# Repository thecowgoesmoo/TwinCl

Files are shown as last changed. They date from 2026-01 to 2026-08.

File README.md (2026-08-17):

# TwinCl
A modern clavinet design &amp; its digital twin
The instrument is designed in OpenSCAD.  A digital model is built and simulated in MATLAB.  WAV files are bundled into sfz (sforzando sample player VST) patches for play-testing instrument parameter variations.  It is intended to be built from low-cost and easily-sourced materials.

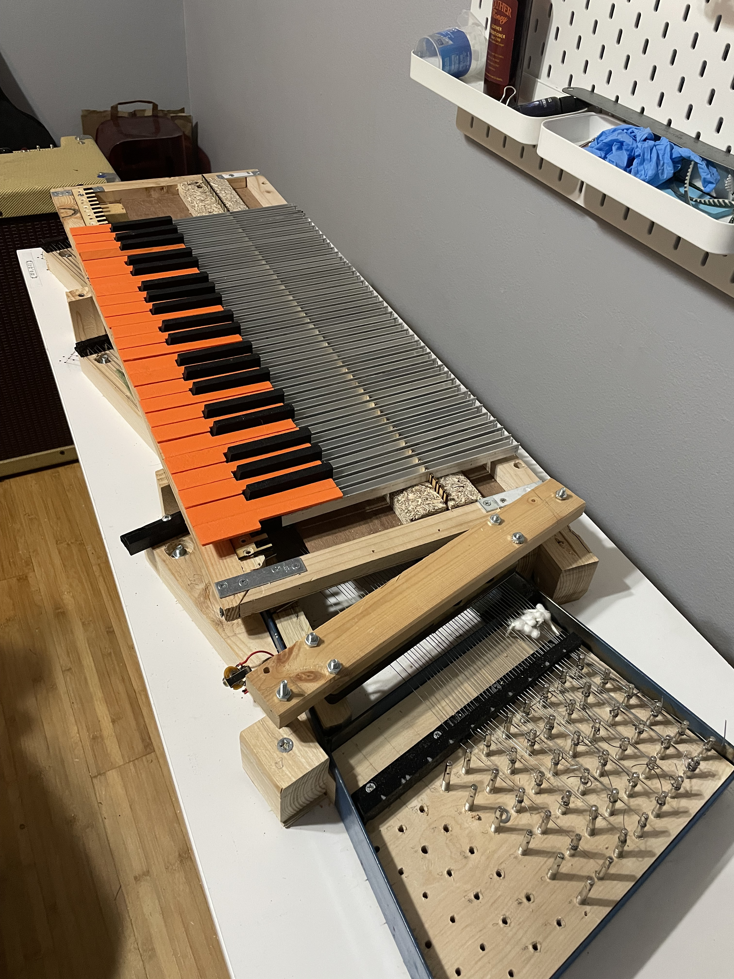
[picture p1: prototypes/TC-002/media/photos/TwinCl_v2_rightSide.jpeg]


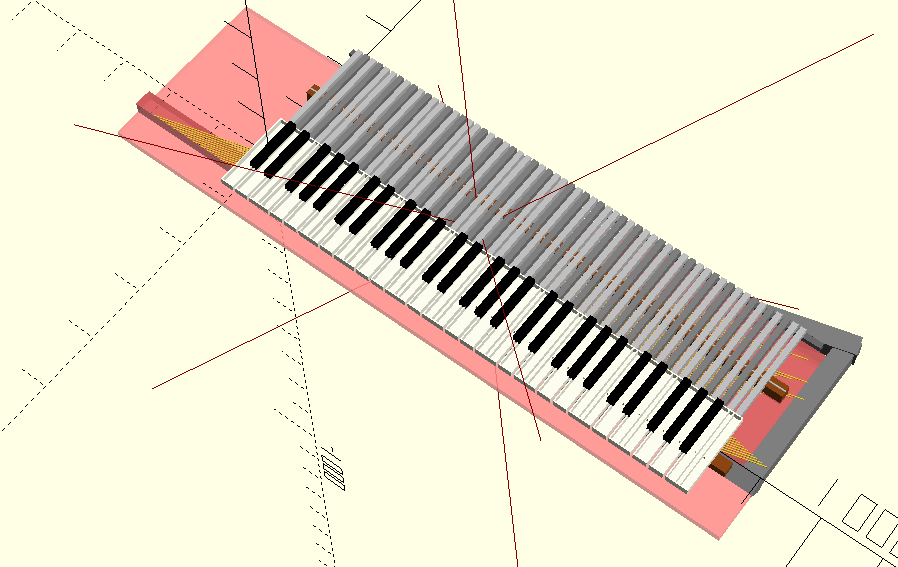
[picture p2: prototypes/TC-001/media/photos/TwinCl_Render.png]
Render


Innovators like Leo Fender imbued the electric guitar with flexibility at a price-point that enabled a several subsequent decades of musical development.  The electromechanical pianos of the mid 20th century introduced new sounds as well, but many factors (including complexity & cost) kept them from displacing the acoustic piano as completely as the electric guitar did for its arched hollow predecessors.  The advent of the ROM-based electronic keyboards in the 1980's dropped keyboard manufacturing costs by an order of magnitude while also bringing more convincing piano sounds to consumers.  As a result, nearly all remaining electromechanical keyboard instruments are refurbished holdovers from the 1950's to 1970's.  

Our intepretation of sound will always be rooted in the physical world, though.  And the vibrating string is the musical archetype.  With that motivation, I seek here to design an instrument modeled after the Clavinet with the following goals:

-Portable (target weight of 50 lbs or less)

-Affordable (bill of materials costing hundreds, not thousands)

-Low-cost manufacturing (target labor of less than 2 person-days)

-Re-use of commerically available materials where possible

-Parametric CAD scripts, to ease customization

-Explore collaborative design with AI LLM's

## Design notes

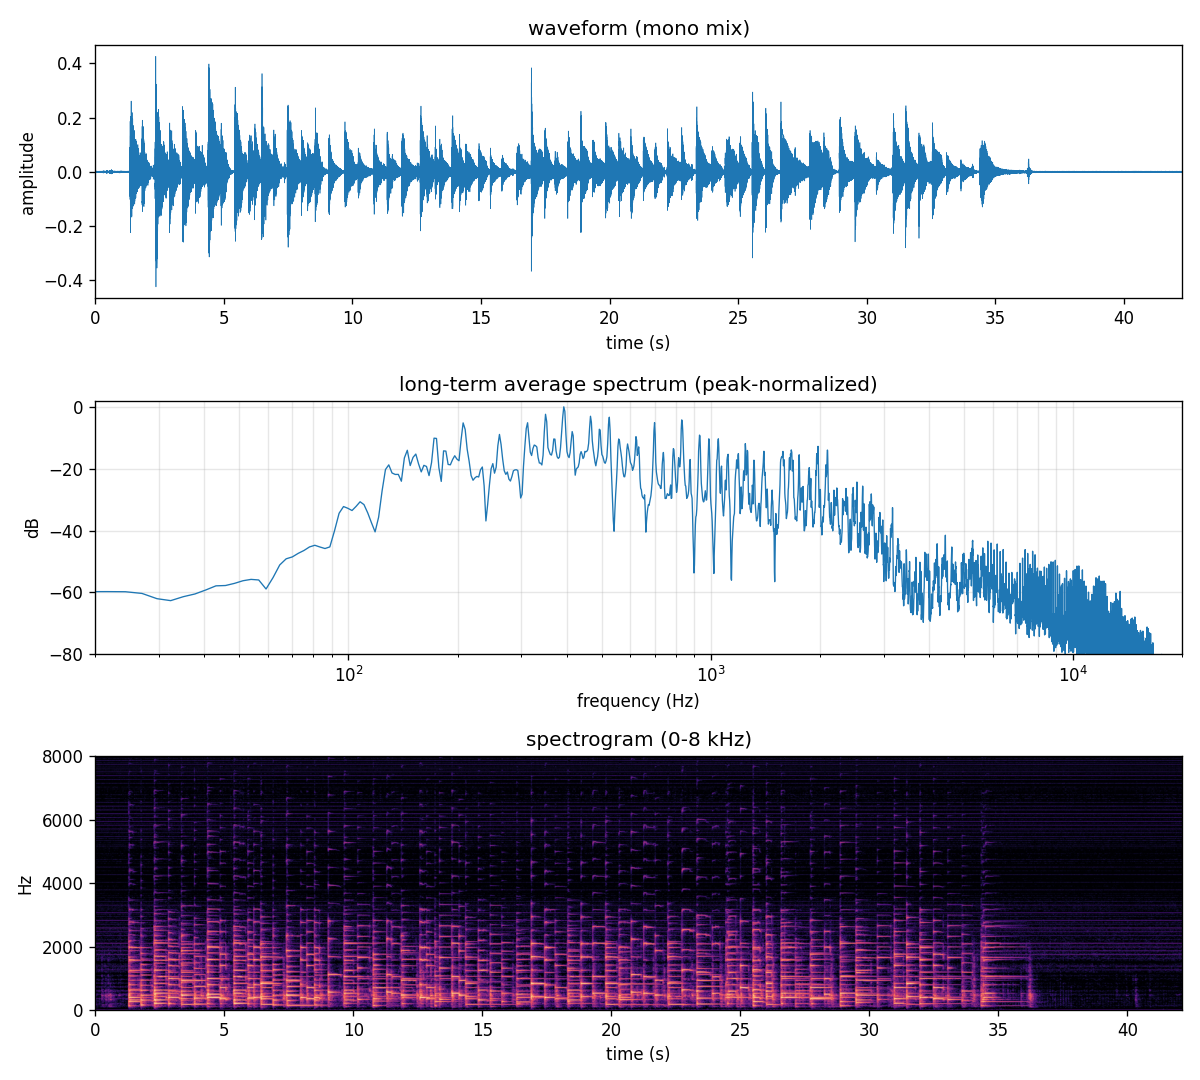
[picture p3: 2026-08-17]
tc002_overview.png

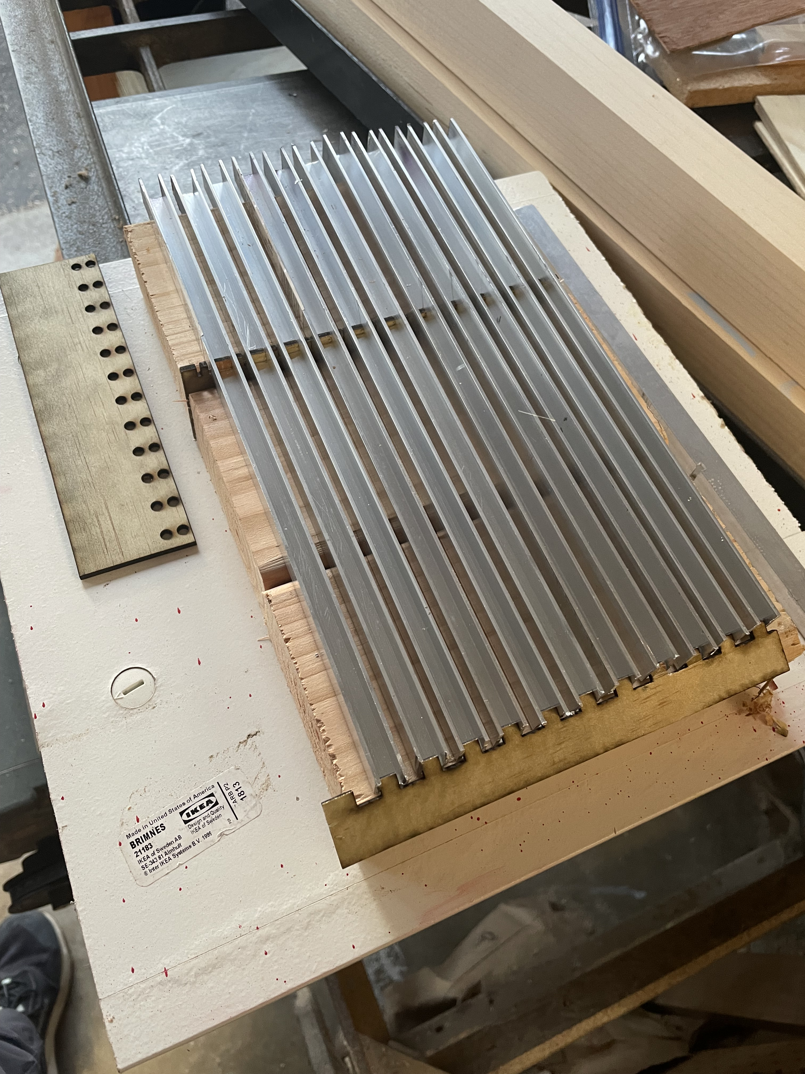
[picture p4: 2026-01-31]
prototypes/TC-001/media/photos/octave_keyChassis_mockup.jpeg

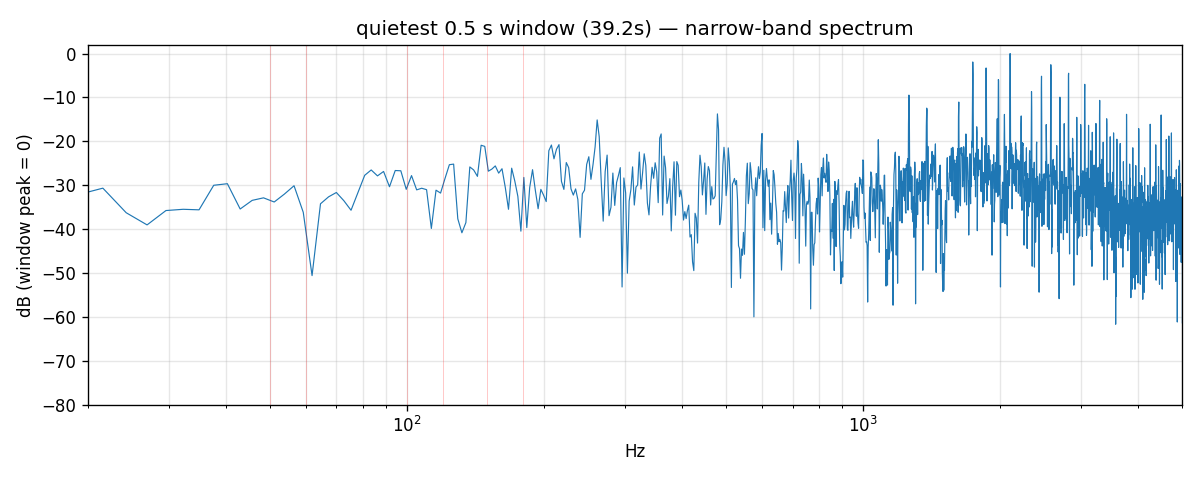
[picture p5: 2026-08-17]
tc002_quiet_spectrum.png

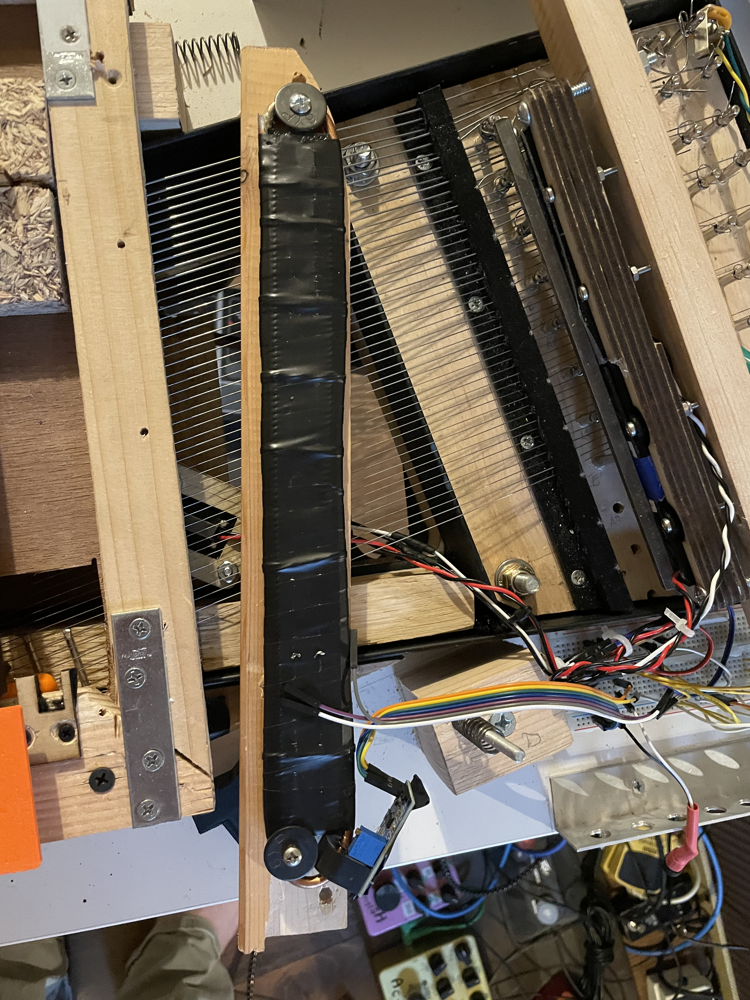
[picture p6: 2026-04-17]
prototypes/TC-002/media/photos/TwinCl_v2_CSTbasedPickup.jpeg

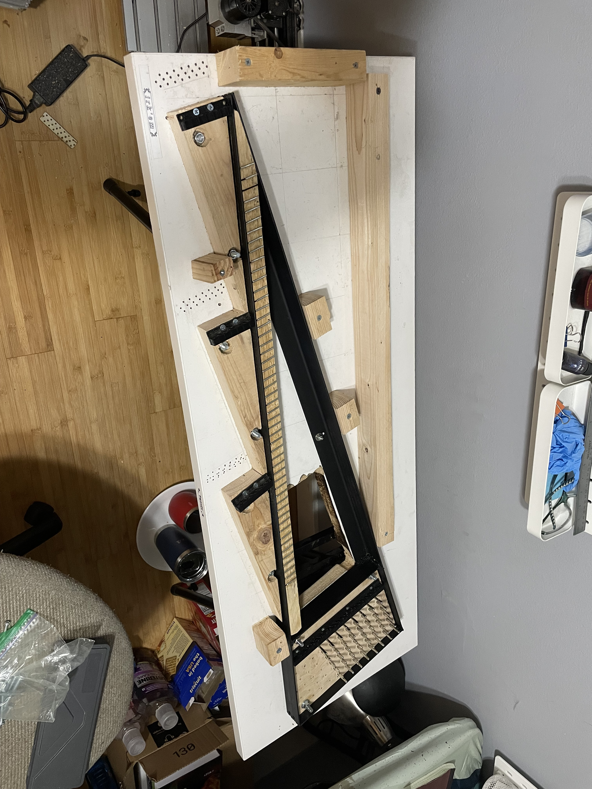
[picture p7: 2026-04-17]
prototypes/TC-002/media/photos/TwinCl_v2_HarpPUaccessCut.jpeg

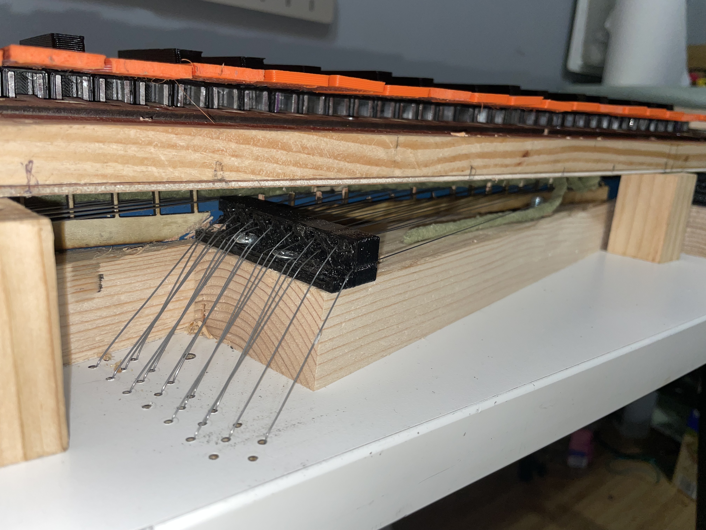
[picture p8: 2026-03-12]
prototypes/TC-002/media/photos/TwinCl_v2_stringEnds.jpeg

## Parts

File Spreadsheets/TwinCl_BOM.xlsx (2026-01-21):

Part name | Part detail | Quantity | Source link | Unit price | Line total price | Weight | Line total weight
String thick 1 | 0.036" wound electric guitar string | 3 | https://www.stringsandbeyond.com/daddario-electric-guitar-single-string-nw036.html | $1.79 | $5.37 | 0 |  | Prolly gotta use guitar strings
String thick 2 | 0.024" wound electric guitar string | 5 | https://www.stringsbymail.com/daddario-nw024-xl-nickel-wound-electric-string-024-gauge-single-4358.html | $1.59 | $7.95 | 0 |  | Prolly gotta use guitar strings
String thick 3 | 0.016" electric guitar string | 10 | https://www.ellismusic.com/p-1560-daddario-pl016-plain-steel-guitar-single-string-016.aspx | $1.50 | $15.00 | 0 |  | Much cheaper in bulk spools
String thick 4 | 0.0105" electric guitar string | 8 | https://www.musicstore.com/en_US/USD/D-Addario-NYS0105/art-GIT0040832-000 | $2.33 | $18.64 | 0 |  | Much cheaper in bulk spools
String thick 5 | 0.009" electric guitar string | 35 | https://www.stewmac.com/strings-and-accessories/strings/electric-guitar-strings/daddario-single-electric-guitar-strings/ | $1.12 | $39.20 | 0 |  | Much cheaper in bulk spools
Rubber vac line tips | 1/8" inner diameter, set of 20 | 3 | https://www.amazon.com/110-Assortment-Carburetor-Manifold-Automotive/dp/B0CX1NCHK8 | $9.97 | $29.91 | 0
Zither tuning pins |  | 3 | https://www.amazon.com/dp/B08QTP1F5F?ref_=ppx_hzsearch_conn_dt_b_fed_asin_title_1 | $12.99 | $38.97 | 0 |  | Gotta be a cheaper source
keys | 1" x 2" x 12" fir lumber | 91.5 |  | $0.50 | $45.75 | 35 | 22.24
tuning pin block | 2" x 2" x 48" hard rock maple | 1 |  |  | $0.00 | 44 | 4.89
ball-end & bridge block | 12" x 8" x 2" hard rock maple | 1 |  |  | 0 | 44 | 3.67
Frame base | 48" x 18" x 0.5" | 1 | https://www.homedepot.com/p/SANDEPLY-12mm-Sande-Plywood-1-2-in-Category-x-4-ft-x-8-ft-Actual-0-472-in-x-48-in-x-96-in-454532/203414055 | $11.25 | $11.25 | 40 | 6.67
Octave pivot combs | Staggered & doubled up | 10 | laser-cut in house from 3 mm ply | $0.08 | $0.75 | 0
Rear key guides | Staggered & doubled up | 10 | laser-cut in house from 3 mm ply | $0.08 | $0.75 | 0
Front key guides | Staggered & doubled up | 10 | laser-cut in house from 3 mm ply | $0.08 | $0.75 | 0
Harp anvil-front | 1.25" x 1.25" x 48" bed rail | 1 | https://www.amazon.com/Amazon-Basics-6-Leg-Support-Frame/dp/B07D4BD5D3?sp_csd=d2lkZ2V0TmFtZT1zcF9hdGY | $3.00 | $3.00 |  | 5 | Bed frames available for 0-$20 on FB marketplace
Harp treble-side | 1.25" x 1.25" x 18" bed rail | 1 | https://www.amazon.com/Amazon-Basics-6-Leg-Support-Frame/dp/B07D4BD5D3?sp_csd=d2lkZ2V0TmFtZT1zcF9hdGY | $3.00 | $3.00 |  | 3 | Bed frames available for 0-$20 on FB marketplace
Harp skew-side | 1.25" x 1.25" x 60" bed rail | 1 | https://www.amazon.com/Amazon-Basics-6-Leg-Support-Frame/dp/B07D4BD5D3?sp_csd=d2lkZ2V0TmFtZT1zcF9hdGY | $3.00 | $3.00 |  | 5 | Bed frames available for 0-$20 on FB marketplace
Gusset plates | 3" x 3" x 0.25" steel | 3 |  |  | $0.00 |  | 0.5 | Steel electric junction box covers?
1/4-20 bolts | 1" long Grade 5 or Grade 8 | 12 | https://www.austinhardware.com/1-4-20-ny-ins-lock-nut-waxed-18-8-s-s.html | $0.23 | $2.76 | 0 | 0.5
1/4-20 nuts | With nylon locking inserts | 12 | https://boltdepot.com/Product-Details?product=2554 | $0.15 | $1.80 | 0
Pickups | Single-coil-sized blade humbucking | 6 | https://www.musicstore.com/en_US/USD/Guitars/Humbucker-in-Single-Coil-Format/cat-GITARRE-GITESCHU | $29.40 | $176.40 | 0 | 1 | Ridiculous. Consider PCB-based pickups?
Preamp & control PCB | Custom design, made by JLCPCB | 1 | JLCPCB | $5.00 | $5.00 | 0
 |  |  |  |  | $409.25 | Could reduce by ~$200 with in-house pickup building and bulk music wire

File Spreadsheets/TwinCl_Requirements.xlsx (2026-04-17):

Full unit | Total weight less than 50 lbs
Full unit | Fits within a 48” x 24” x 8” volume
Full unit | Has fixed wheels on one end to ease transport
Full unit | Has corner/edge bump protection
Action | Keys play with 0.5 Newtons of force
Action | Keys do not interfere-with/rub each other
Action | Keys return within 100 ms of release
Action | Keywork makes less than 50 dBA of noise during play (excluding any string noise)
Harp | Accommodates 60 keys with pitches from F1 to E6
Harp | Handles up to 30 lbf per string when fully strung
Electronics | Has a bridge pickup that runs along the non-keyboard end of the string harp (within 1 inch of the string ends)
Electronics | Bridge pickup height adjustable over a distance from 0-0.25 inches between the magnet pole bar and the string plane
Electronics | Has a neck pickup that runs along a 1/5 string length diagonal from the non-keyboard end of the string harp
Electronics | Neck pickup height adjustable over a distance from 0-0.25 inches between the magnet pole bar and the string plane
Electronics | Preamp facilitates pickup switching combinations: neck only, bridge only, neck and bridge in-phase, neck and bridge out-of-phase
Electronics | 1.5 V RMS output amplitude during typical play
Electronics | 60Hz/120Hz noise amplitude < 50mV RMS
Electronics | Output from 100 Hz to 10 kHz
Manufacturability | Bill of Materials total less than $500
Manufacturability | Can be fabricated from materials in BOM (Bill of Materials) using tools in the irk’em HackCave

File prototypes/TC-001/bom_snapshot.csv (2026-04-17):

Part name | Part detail | Quantity | Source link | Unit price | Line total price | Weight (lb) | Line total weight (lb) | Notes
# TODO: Copy rows from Spreadsheets/TwinCl_BOM.xlsx that apply to this build | with quantities as-built.

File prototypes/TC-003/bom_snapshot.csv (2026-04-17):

Part name | Part detail | Quantity | Source link | Unit price | Line total price | Weight (lb) | Line total weight (lb) | Notes
# TODO: Fill in as parts are acquired/fabricated for this build.

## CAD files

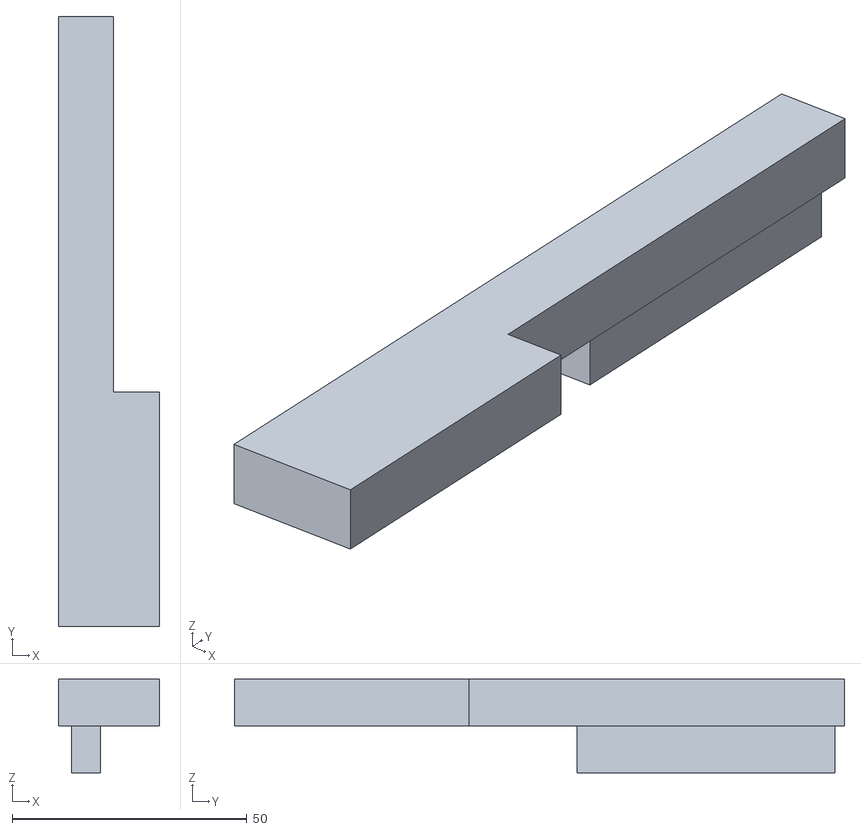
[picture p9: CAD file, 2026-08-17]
CAD/irkem_C_keycapsForWoodcut_v1.stl
21.6 x 130.0 x 20.0

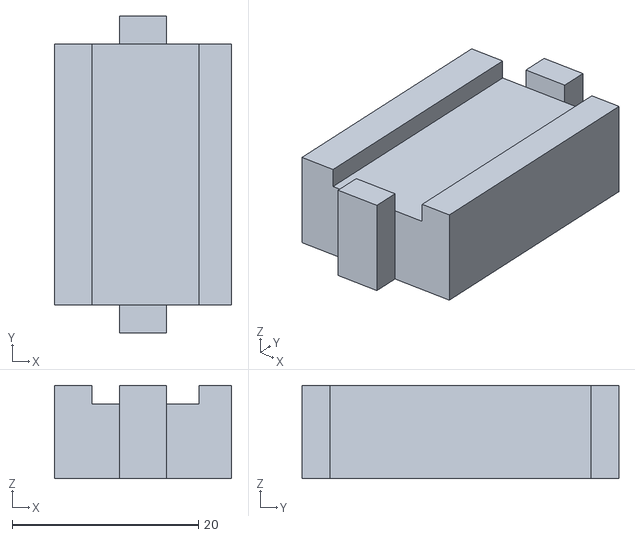
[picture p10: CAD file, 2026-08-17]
print_files/irkem_controlSwitchCapV2.stl
19.0 x 34.0 x 10.0

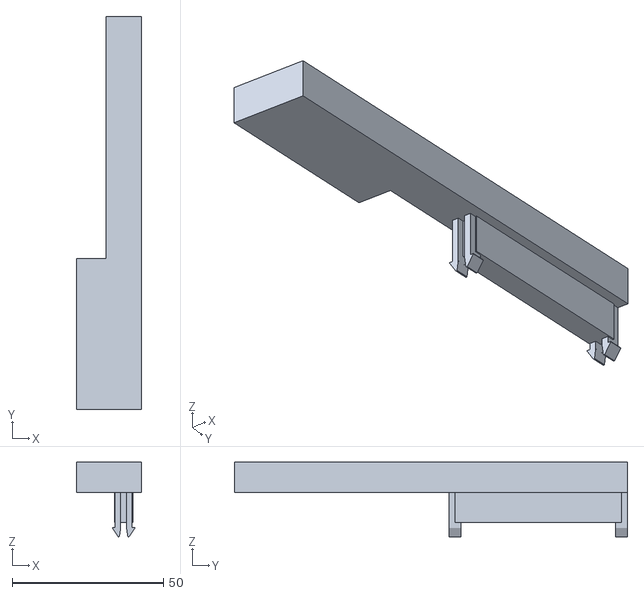
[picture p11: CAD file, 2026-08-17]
print_files/irkem_B_keycapsToPrint_v6.stl
21.6 x 130.0 x 24.8

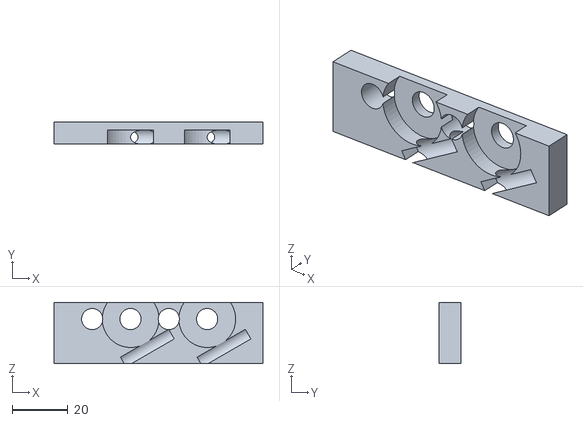
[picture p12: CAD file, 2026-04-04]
CAD/irkem_FineTunersV2.stl
75.0 x 8.00 x 22.0

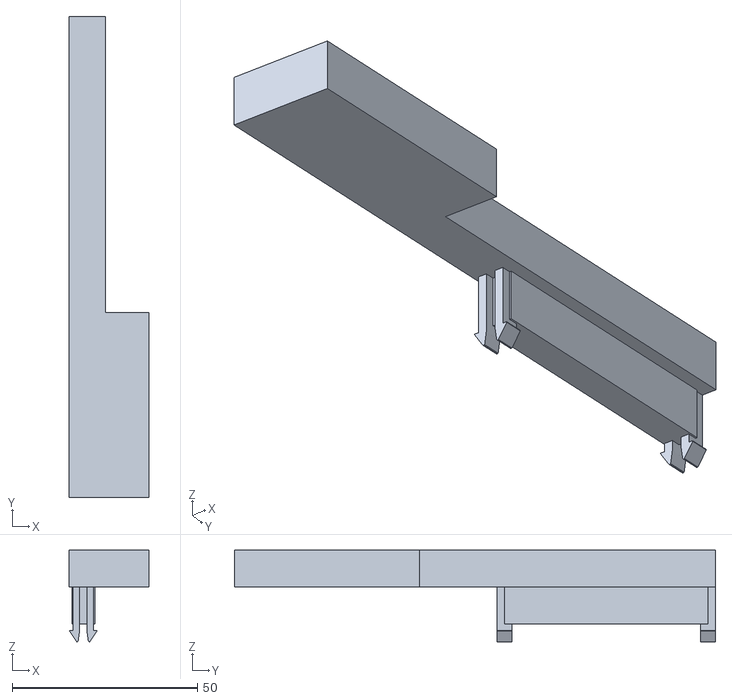
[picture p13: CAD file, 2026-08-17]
print_files/irkem_F_keycapsToPrint_v6.stl
21.6 x 130.0 x 24.8

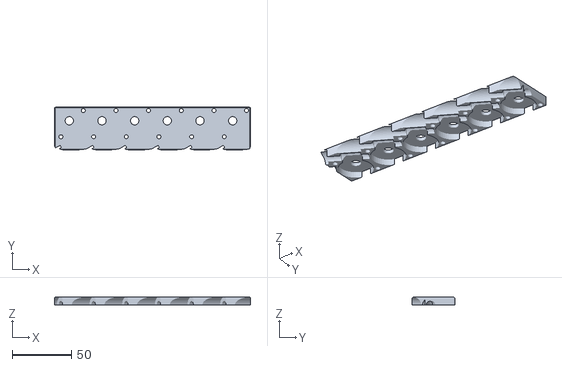
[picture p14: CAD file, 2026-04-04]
CAD/irkem_TwGrCsTopV2.stl
165.0 x 35.8 x 6.60

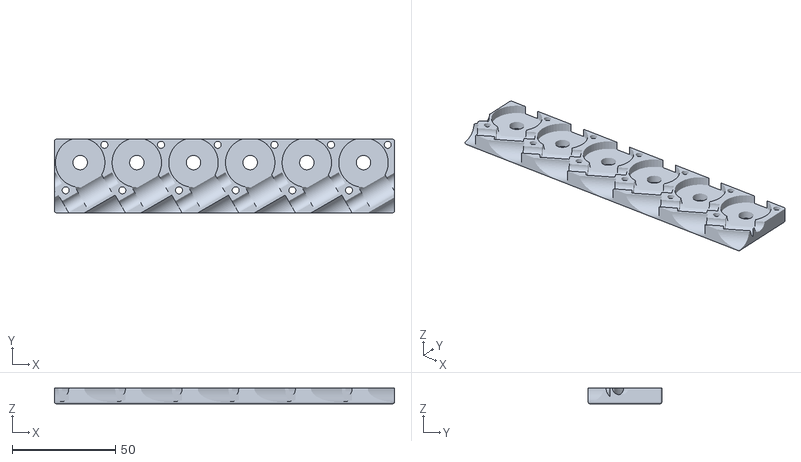
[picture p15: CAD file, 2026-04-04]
CAD/irkem_TwGrCsBotV2.stl
165.0 x 35.8 x 7.60

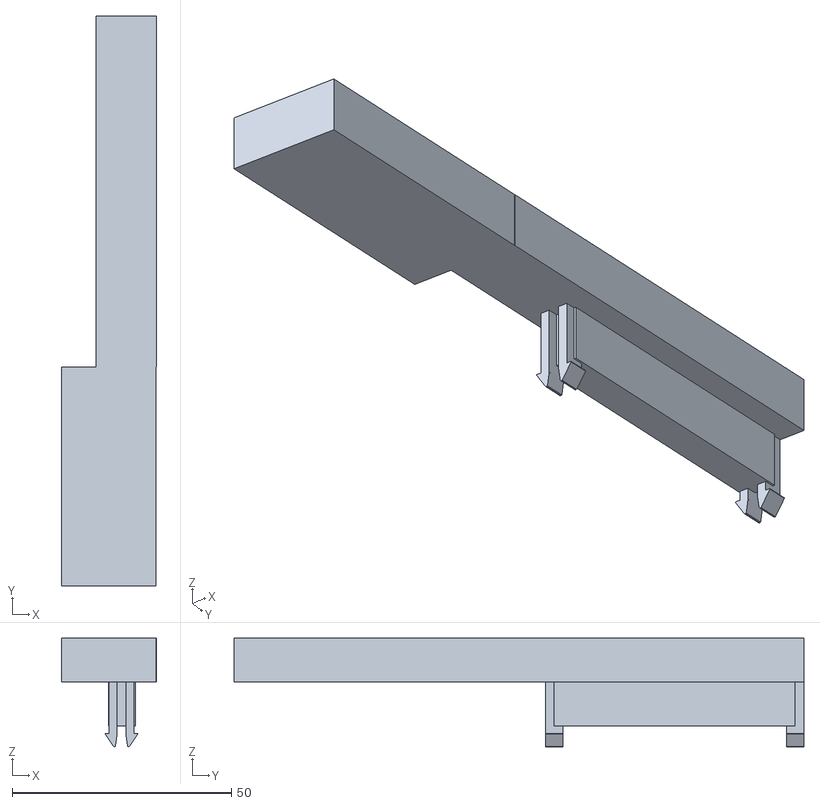
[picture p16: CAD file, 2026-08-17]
print_files/irkem_E_keycapsToPrint_v6.stl
21.6 x 130.0 x 24.8

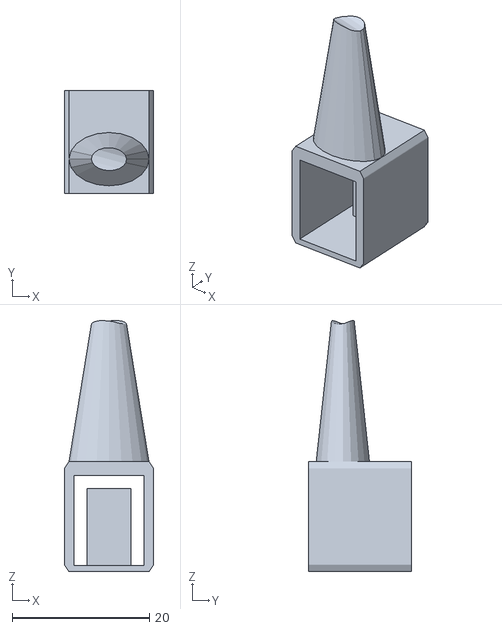
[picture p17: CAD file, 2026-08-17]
print_files/irkem_hammerTips_v4.stl
13.0 x 15.0 x 36.6

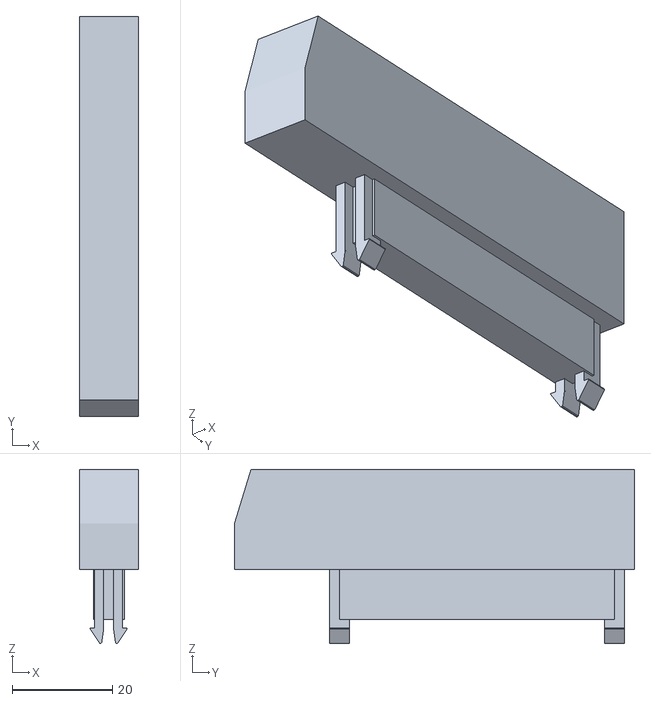
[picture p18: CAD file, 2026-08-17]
print_files/irkem_sharp_keycapsToPrint_v6.stl
11.8 x 80.0 x 34.8

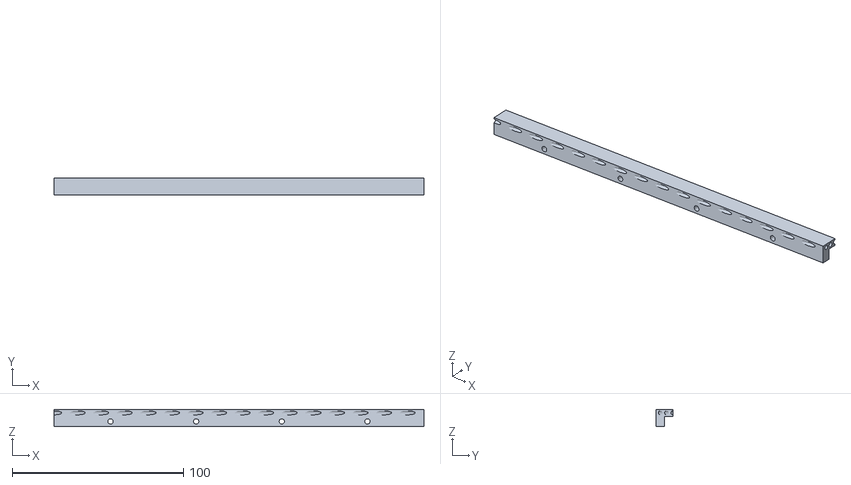
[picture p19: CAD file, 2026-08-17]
print_files/irkem_eatonStripEnds_v2.stl
216.0 x 10.0 x 10.0

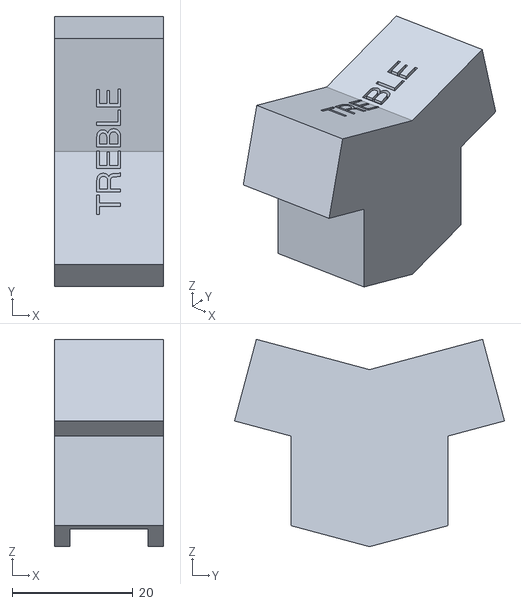
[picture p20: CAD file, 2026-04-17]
print_files/irkem_TwinCl_SwitchRockerTREBLEv3.stl
18.0 x 44.7 x 34.4

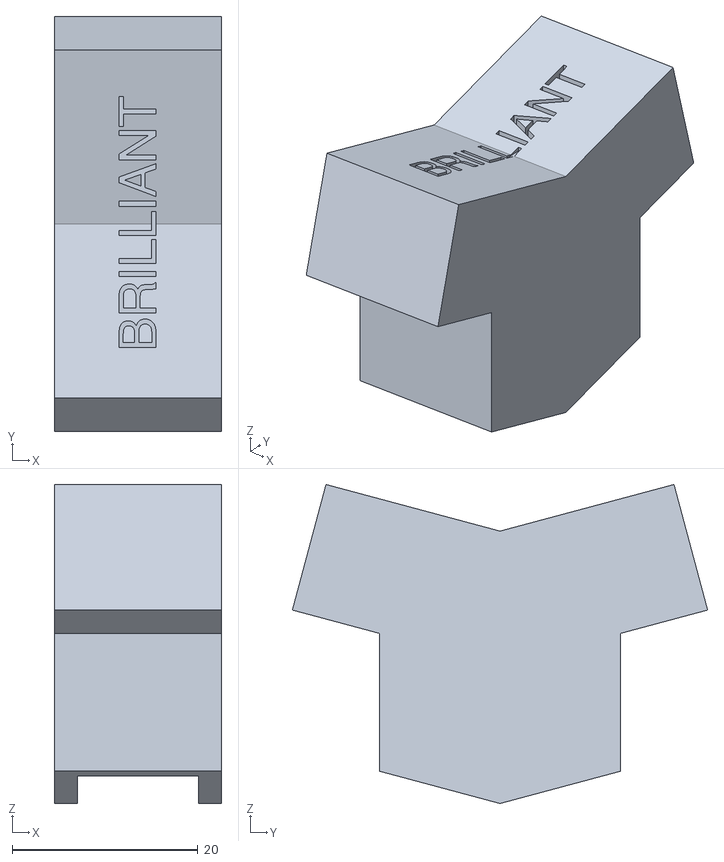
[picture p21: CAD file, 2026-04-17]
print_files/irkem_TwinCl_SwitchRockerBRILLIANTv3.stl
18.0 x 44.7 x 34.4

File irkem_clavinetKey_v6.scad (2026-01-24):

// ==========================================
// PARAMETRIC CLAVINET KEY DESIGN (V7 - Laser SVG)
// ==========================================

/* [Render Mode] */
// Select "Laser_SVG" to see the red cutting paths
mode = "Assembly";//"Laser_SVG"; // [Assembly, Laser_SVG, Chassis_DXF, Cap_STL, Tip_Holder_STL, Pivot_Insert_STL]

/* [Key Dimensions] */
chassis_length = 320;
u_outer_width = 9.525; // 3/8 inch
u_height = 12.7;       // 1/2 inch
wall_thickness = 1.5;  // Approx 1/16 inch
chassis_height = u_height;

/* [Action Geometry] */
strike_point_offset = 85;
pivot_hole_inset = 100;
bolt_size = 3;

// Calculated Positions
pivot_y = chassis_length - pivot_hole_inset;
// IMPORTANT: Moved to 55mm so it catches the Black keys (which start at 45mm)
upstop_y = 55; 
spring_anchor_y = chassis_length; 

/* [Fabrication Vars] */
kerf_width = 3.175;   // 1/8" saw blade width
comb_thickness = 3.0; // Laser cut material thickness
comb_tolerance = 0.1; // Extra clearance for the comb teeth

/* [Key Cap] */
cap_width = 23.5; 
cap_length = 140; 
black_key_front_y = 45;

/* [Hidden] */
$fn = 40;
inner_width = u_outer_width - (wall_thickness*2);

// Standard Geometric Spacing for 164.5mm Octave
// C=0, C#=1, D=2, etc.
key_offsets = [
    0,      // C
    13.7,   // C#
    23.5,   // D
    38.8,   // D#
    47.0,   // E
    70.5,   // F
    82.3,   // F#
    94.0,   // G
    108.3,  // G#
    117.5,  // A
    131.8,  // A#
    141.0   // B
];

// Which keys are Black? (Indices 1, 3, 6, 8, 10)
function is_black(i) = (i==1 || i==3 || i==6 || i==8 || i==10);

// ==========================================
// MAIN RENDER SWITCH
// ==========================================

if (mode == "Assembly") {
    assembly_octave();
} else if (mode == "Laser_SVG") {
    // 2D Projection for Laser Cutting
    color([1,0,0]) // RGB Red (255, 0, 0)
    projection(cut=true) 
        translate([0,0,-0.5]) // Slices through the Z=0 plane of the layout
        layout_for_laser();
} else if (mode == "Pivot_Insert_STL") {
    pivot_insert();
} else if (mode == "Tip_Holder_STL") {
    tip_holder();
}

// ==========================================
// LASER LAYOUT MODULE
// ==========================================

module layout_for_laser() {
    // We lay the 3 combs flat on the XY plane for projection.
    // Bed Size: 300 x 200
    
    // 1. Up-Stop Comb (Top Strip)
    translate([10, 150, 0]) 
        rotate([90,0,0]) // Rotate to lay flat
        comb_generator("upstop");

    // 2. Fulcrum Comb (Middle Strip)
    translate([10, 100, 0]) 
        rotate([90,0,0]) 
        comb_generator("pivot");

    // 3. Spring Anchor Comb (Bottom Strip)
    translate([10, 50, 0]) 
        rotate([90,0,0]) 
        comb_generator("anchor");
}

module comb_generator(type) {
    // Generates a ganged comb for the full octave
    // type: "upstop", "pivot", "anchor"
    
    // Total length of the comb strip (approx 165mm + margins)
    strip_len = 166; 
    
    difference() {
        // The Stock Material Strip
        if (type == "upstop") {
            translate([-10, upstop_y, -5]) 
                cube([strip_len + 20, 3, 20]);
        } else if (type == "pivot") {
            translate([-10, pivot_y - comb_thickness/2, -10]) 
                cube([strip_len + 20, comb_thickness, 20]);
        } else if (type == "anchor") {
            translate([-10, spring_anchor_y, -25]) 
                cube([strip_len + 20, 3, 20]);
        }

        // Subtract the Keys
        // We loop through the 12 semi-tones
        for (i = [0 : 11]) {
            translate([key_offsets[i], 0, 0]) {
                // Determine if this key is Black or White
                if (is_black(i)) {
                    // Subtract Black Key
                     minkowski() {
                        key_chassis(is_white=false);
                        cube([comb_tolerance, comb_tolerance, comb_tolerance], center=true);
                    }
                } else {
                    // Subtract White Key
                    minkowski() {
                        key_chassis(is_white=true);
                        cube([comb_tolerance, comb_tolerance, comb_tolerance], center=true);
                    }
                }
            }
        }
        
        // Add Mounting Holes to the ends of the strip?
        // (Optional: Un-comment to add 3mm mounting holes)
        /*
        translate([-5, (type=="pivot"?pivot_y:upstop_y), 0]) rotate([90,0,0]) cylinder(d=3, h=10, center=true);
        translate([strip_len + 5, (type=="pivot"?pivot_y:upstop_y), 0]) rotate([90,0,0]) cylinder(d=3, h=10, center=true);
        */
        
        // For Anchor: Add the spring holes manually if subtraction didn't catch them
        if (type == "anchor") {
             for (i = [0 : 11]) {
                translate([key_offsets[i] + 15, spring_anchor_y, 15]) 
                    rotate([90,0,0]) cylinder(r=1, h=10, center=true);
             }
        }
    }
}

// ==========================================
// VISUALIZATION ASSEMBLY
// ==========================================

module assembly_octave() {
    // Visualizes the full octave with keys
    for (i = [0 : 11]) {
        translate([key_offsets[i], 0, 0]) {
            if (is_black(i)) {
                // Black Key
                color("gray") key_chassis(is_white=false);
                translate([0,0,chassis_height+8]) color("black") key_cap_b();
                translate([-inner_width/2, pivot_y - 6, wall_thickness]) color("cyan") pivot_insert();
            } else {
                // White Key
                color("silver") key_chassis(is_white=true);
                translate([0,0,chassis_height]) color("ivory") key_cap_w();
                translate([-inner_width/2, pivot_y - 6, wall_thickness]) color("cyan") pivot_insert();
            }
        }
    }
    // Show the Combs in place
    guides_octave();
}

module guides_octave() {
    color("brown") comb_generator("upstop");
    color("brown") comb_generator("pivot");
    color("brown") comb_generator("anchor");
}

// ==========================================
// COMPONENT MODULES (Unchanged Logic)
// ==========================================

module key_chassis(is_white=true) {
    start_y = is_white ? 0 : black_key_front_y; 
    difference() {
        difference() {
            translate([-u_outer_width/2, 0, 0])
                cube([u_outer_width, chassis_length, u_height]);
            translate([-inner_width/2, -1, wall_thickness])
                cube([inner_width, chassis_length + 2, u_height + 1]);
        }
        if (!is_white) {
             translate([-u_outer_width, -10, -1])
                cube([u_outer_width*3, start_y + 10, u_height*3]);
        }
        // Pivot Slot
        translate([-u_outer_width/2-1, pivot_y - kerf_width/2, -1])
            cube([u_outer_width+2, kerf_width, 5]);
        // Tip Holes
        translate([-10, chassis_length - strike_point_offset - cap_length, u_height/2]) {
             translate([0, 6, 0]) rotate([0,90,0]) cylinder(d=bolt_size, h=20);
             translate([0, -6, 0]) rotate([0,90,0]) cylinder(d=bolt_size, h=20);
        }
        // Cap Hole
        translate([0, start_y + 15, u_height/2]) cylinder(d=bolt_size, h=20);
    }
}

module key_cap_w() {
    // (Simplified for SVG speed, geometry maintained)
    difference() {
        union() {
            translate([-cap_width/2, 0, 0]) cube([cap_width, cap_length, 12]);
            translate([-u_outer_width/2 - 2, black_key_front_y, -5]) cube([u_outer_width + 4, 30, 5]);
        }
        translate([-u_outer_width/2, black_key_front_y-1, -5.1]) cube([u_outer_width, 32, 5.2]);
        translate([0, black_key_front_y + 15, -10]) cylinder(d=bolt_size, h=40);
    }
}

module key_cap_b() {
    cap_b_len = cap_length - black_key_front_y;
    difference() {
        translate([-cap_width/4, black_key_front_y, 0]) cube([cap_width/2, cap_b_len, 12]);
        translate([-u_outer_width/2, black_key_front_y-1, -5.1]) cube([u_outer_width, cap_b_len+5, 5.2]);
        translate([0, black_key_front_y + 15, -10]) cylinder(d=bolt_size, h=40);
    }
}

module pivot_insert() {
    fit_tolerance = 0.2; 
    block_w = inner_width - fit_tolerance; 
    block_len = 12;
    block_h = 6; 
    translate([0, 0, 0]) {
        difference() {
            translate([0, 0, block_h/2]) cube([block_w, block_len, block_h], center=true);
            hull() {
                translate([0, 0, -1]) cube([comb_thickness + 0.2, 4, block_h+2], center=true);
                translate([0, 0, block_h]) cube([comb_thickness + 0.5, 6, 1], center=true); 
            }
        }
    }
}
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

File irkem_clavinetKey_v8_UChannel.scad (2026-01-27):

// ==========================================
// PARAMETRIC CLAVINET KEY DESIGN (V4 - U-Channel & Combs)
// ==========================================
chassis_length = 270;//320;
/* [Render Mode] */
mode = "Assembly"; // [Assembly, Chassis_DXF, Cap_STL, Tip_Holder_STL, Pivot_Insert_STL]

/* [Key Dimensions] */
chassis_length = 320;
// -- U-CHANNEL DIMENSIONS --
u_outer_width = 9.525; // 3/8 inch
//u_height = //12.7;       // 1/2 inch
wall_thickness = 1.5;  // Approx 1/16 inch
u_height = 12.7;
chassis_height = u_height;

/* [Action Geometry] */
strike_point_offset = 115;//85;
tip_clearance = 6;
pivot_hole_inset = 100;
bolt_size = 3;

// Calculated Positions
pivot_y = chassis_length - pivot_hole_inset;
upstop_y = -20;//30; 
spring_anchor_y = chassis_length; // At the tail

/* [Fabrication Vars] */
kerf_width = 3.175; // 1/8" saw blade width
comb_thickness = 3.0; // Laser cut material thickness

/* [Key Cap] */
cap_width = 23.5; 
cap_length = 140; 
cap_wall = 2;
black_key_front_y = 45;

/* [Hidden] */
$fn = 40;
inner_width = u_outer_width - (wall_thickness*2);

// ==========================================
// MAIN RENDER SWITCH
// ==========================================

if (mode == "Assembly") {
    //assembly_w();
} else if (mode == "Chassis_DXF") {
    projection() rotate([0,90,0]) key_chassis();
} else if (mode == "Cap_STL") {
    rotate([180,0,0]) key_cap_w();
} else if (mode == "Tip_Holder_STL") {
    tip_holder();
} else if (mode == "Pivot_Insert_STL") {
    pivot_insert();
}


// ==========================================
// ASSEMBLIES
// ==========================================

module assembly_w() {
    // White Key
    color("silver") key_chassis(is_white=true);
    
    translate([0, 0, chassis_height]) 
        color("ivory") translate([0,-50,0]) key_cap_w();
        
    translate([0, chassis_length - strike_point_offset - cap_length, 0]) 
        rotate([180,0,0])
        color("orange") tip_holder();

    // The new 3D printed bearing insert
    //translate([-0*u_outer_width/2 + 0*wall_thickness, pivot_y, wall_thickness])
        //rotate([0,0,90])
        //color("cyan") pivot_insert();

    guides();
}

module assembly_b() {
    // Black key
    color("silver") key_chassis(is_white=true);
    
    translate([0, 0, chassis_height]) 
        color("black") translate([0,-50,0]) key_cap_b();
        
    translate([0, chassis_length - strike_point_offset - cap_length, 0]) 
        rotate([180,0,0])
        color("orange") tip_holder();

    // The new 3D printed bearing insert
    //translate([-0*u_outer_width/2 + 0*wall_thickness, pivot_y, wall_thickness])
        //rotate([0,0,90])
        //color("cyan") pivot_insert();

    guides();
}

// ==========================================
// COMPONENT MODULES
// ==========================================

module key_chassis(is_white=true) {
    // The Aluminum U-Channel (OPEN SIDE UP)
    // Z=0 is the bottom web (outside). 
    start_y = is_white ? 0 : black_key_front_y; 
    
    difference() {
        // 1. The U-Channel Extrusion
        difference() {
            // Solid Block
            translate([-u_outer_width/2, 0, 0])
                cube([u_outer_width, chassis_length, u_height]);
            // Inner Cavity (Open at Top)
            translate([-u_outer_width/2 + wall_thickness, -1, wall_thickness])
                cube([inner_width, chassis_length + 2, u_height + 1]);
        }

        // -- CUTOUTS --
        // 2. Front Truncation (For Black Keys)
        if (!is_white) {
             translate([-u_outer_width, -10, -1])
                cube([u_outer_width*3, start_y + 10, u_height*3]);
        }

        // 3. Pivot slot (The Kerf Cut)
        // Cuts through bottom web and slightly up the sides
        translate([-u_outer_width/2-1, pivot_y - kerf_width/2, -1])
            cube([u_outer_width+2, kerf_width, 5]);

        // 4. Tip Holder Holes
        translate([-10, chassis_length - strike_point_offset - cap_length, u_height/2]) {
             translate([0, 6, 0]) rotate([0,90,0]) cylinder(d=bolt_size, h=20);
             translate([0, -6, 0]) rotate([0,90,0]) cylinder(d=bolt_size, h=20);
        }
        
        // 5. Cap Mounting Hole 
        translate([0, start_y + 15, u_height/2]) 
            cylinder(d=bolt_size, h=20);
    }
}

module pivot_insert() {
    // A 3D printed block that fits INSIDE the U-channel.
    // It captures the comb to prevent fore/aft slop.
    
    fit_tolerance = 0.2; // Clearance for inserting into aluminum
    block_w = inner_width - fit_tolerance; 
    block_len = 12;
    block_h = 6;
    
    // Positioned centered on origin for easy export
    translate([-block_len/2, -block_w/2, 0]) {
        difference() {
            // Main body
            cube([block_len, block_w, block_h]);
            
            // The Comb Slot (Tapered for easy entry)
            // Precise width at the top (pivot point), wider at bottom
            translate([block_len/2 - comb_thickness/2, -1, -1])
                hull() {
                    cube([comb_thickness, block_w+2, block_h+2]); // Straight slot
                    // Or add taper if desired
                }
            
            // Optional: Viewing hole or material saver
            translate([block_len/2, block_w/2, block_h/2])
                rotate([90,0,0])
                cylinder(d=3, h=block_w+2, center=true);
        }
        
        // Crush Ribs (Tiny bumps to hold it inside the aluminum channel)
        translate([0, -0.2, block_h/2]) cylinder(r=0.4, h=block_h, $fn=3);
        translate([block_len, -0.2, block_h/2]) cylinder(r=0.4, h=block_h, $fn=3);
        translate([0, block_w+0.2, block_h/2]) cylinder(r=0.4, h=block_h, $fn=3);
        translate([block_len, block_w+0.2, block_h/2]) cylinder(r=0.4, h=block_h, $fn=3);
    }
}

module guides() {
    // -- 1. Front Up-Stop Comb --
    // Positioned using upstop_y
    color("brown", 0.6) difference(){ 
    translate([-15, upstop_y, wall_thickness]) 
        cube([30, 25, 3]); // Visual placeholder for the comb bar
        key_chassis(is_white=true);
    }
    
    // -- 2. Fulcrum Comb --
    // Positioned using pivot_y
    // This represents the stationary laser-cut steel/plywood sheet
    color("brown", 0.6) 
    difference(){
        translate([-15, pivot_y - comb_thickness/2, -7]) 
        cube([30, comb_thickness, 15]);
        translate([0,0,0]) rotate([0,0,0]) key_chassis(is_white=true);
    }

    // -- 3. Rear Key-Spring Anchor --
    // Positioned at the tail
    color("brown", 0.6) 
    translate([-15, spring_anchor_y, -25]) 
        difference() {
            cube([30, 3, 20]);
            // Hole for spring hook
            translate([15, 5, 15]) rotate([90,0,0]) cylinder(r=1, h=10);
        }
    
    // Spring Visualization
    color("gray", 0.5) 
        hull() {
            translate([0, spring_anchor_y, 0]) sphere(r=1);
            translate([0, spring_anchor_y, -15]) sphere(r=1);
        }
}

module key_cap_w() {
    // (Kept largely the same, just ensured parametric fit)
    difference() {
        union() {
            translate([-cap_width/2, 0, 0])
                cube([cap_width, cap_length, 12]);
            // Saddle huggers
            translate([-u_outer_width/2 - 2, black_key_front_y, -5])
                cube([u_outer_width + 4, 30, 5]);
        }
        // Slot for U-Channel
        translate([-u_outer_width/2, black_key_front_y-1, -5.1])
            cube([u_outer_width, 32, 5.2]);
        // Hollow
        translate([-cap_width/2 + 2, 2, 2])
            cube([cap_width - 4, cap_length - 4, 15]);
        // Screw hole
        translate([0, black_key_front_y + 15, -10])
            cylinder(d=bolt_size, h=40);
    }
}

module key_cap_b() {
    // (Kept largely the same, just ensured parametric fit)
    difference() {
        //union() {
        //    translate([-cap_width/2, 0, 0])
        //        cube([cap_width, cap_length, 12]);
        //    // Saddle huggers
        //    translate([-u_outer_width/2 - 2, black_key_front_y, -5])
        //        cube([u_outer_width + 4, 30, 5]);
        //}
        translate([-cap_width/2+cap_width/4, 50, 12.5])
                cube([12, 90, 12]);
        // Slot for U-Channel
        //translate([-u_outer_width/2, black_key_front_y-1, -5.1])
        //    cube([u_outer_width, 32, 5.2]);
        // Hollow
        //translate([-cap_width/2 + 2, 2, 2])
        //    cube([cap_width - 4, cap_length - 4, 15]);
        // Screw hole
        //translate([0, black_key_front_y + 15, -10])
        //    cylinder(d=bolt_size, h=40);
    }
}
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

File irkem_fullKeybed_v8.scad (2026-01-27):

//include <irkem_clavinetKey_v3_UChannel.scad>
include <irkem_clavinetKey_v8_UChannel.scad>
cap_w = 22+2;       //White key width
n_keys = 61;        //number of keys
chassis_length = 270;
//Length of lowest string (uniform gauge at present)
L0 = 48*25.4;       //Baseline string length
skew = 15;          //String skew angle
str_backlen = 200;
strikeLine_y = 0;
strikeLine_z = 0;
anvil_action_h = 0;//2;
pivot_hole_inset = 100;
chassis_height = 12.8;
bolt_size = 3;

// --- NEW MODULE: Keybed Support Rails ---
module keybed_rails() {
    // Calculate total length of the bed
    bed_len = n_keys * 13.75 + 40;
    x_start = -20; // Start slightly to the left of the first key
    
    // 1. FULCRUM RAIL (Pivot Support)
    // ------------------------------------------------
    // Calculate Pivot Position based on Key Design
    // Key Local Pivot Y = chassis_length - pivot_hole_inset
    // Key Global Y Offset = -95
    pivot_y_global = -95 + (chassis_length - pivot_hole_inset);
    pivot_z_global = 15 + (chassis_height / 2); // Center of the key spine
    
    color("DimGray")
    translate([x_start, tail_y_global - 5-15.5-4.2, 0+15-7+2])
        rotate([-15,0,0]) cube([bed_len, 1.5*25.4, 17]);
    color("DimGray")
    translate([x_start, tail_y_global - 5-15.5-13-28+5.3, 0+15-7-8])
        rotate([15,0,0]) cube([bed_len, 1.5*25.4, 17]);
    
    // 2. SPRING RAIL (Return Mechanism)
    // ------------------------------------------------
    // Located directly under the tail of the key to pull it down.
    tail_y_global = -95 + chassis_length;
    
    // Rail is positioned low to allow spring extension
    color("DimGray")
    translate([x_start, tail_y_global - 5-15.5+100-4.5, 0+15-7-10+2])
        cube([bed_len, 10, 10]);
        
        
    // 3. FRONT GUIDE RAIL (Lateral Stability)
    // ------------------------------------------------
    // Located near the playing end to guide the keys.
    guide_y_global = -95 + 40+35; // Approx 40mm in from front of chassis
    
    // The Rail Base
    color("SaddleBrown")
    translate([x_start, guide_y_global - 10-40, 10.5])
        cube([bed_len, 50, 17]); // Stops just below key bottom (Z=15)
    color("SaddleBrown")
    translate([x_start, guide_y_global - 10-40, 10.5-3])
        cube([bed_len, 330, 3]); // Stops just below key bottom (Z=15)    
    // The Guide Pins (Visual representation)
    // These would slot into the bottom of your keys
    //color("Gold")
    //for(k=[0:n_keys-1]) {
    //    translate([k*13.75, guide_y_global, 14])
    //        cylinder(r=2, h=8); // Pins sticking up
    //}
}

// Render the Rails
keybed_rails();

// --- STRING GENERATION ---

for (i = [0:1:(n_keys-1)]){
    //    //Da stringz:
    //    //Manage gauge changes and their length impacts:
    lenMult = lookup(i, [
 		[ 0, 0.5 ],
 		[ 2, 0.5 ],
 		[ 3, 0.75 ],
 		[ 7, 0.75 ],
       [ 8, 1.0 ],
 		[ 17, 1.0 ],
        [ 18, 1.5 ],
 		[ 25, 1.5 ],
 		[ 26, 2 ],
        [ 70, 2]
 	]);
    strLen = lenMult * L0 * 2^(-i/12);
    translate([i*13.75,0+strikeLine_y,0+strikeLine_z]) rotate([0,90,skew]) cylinder(strLen,1,1);
    translate([i*13.75,0+strikeLine_y,0+strikeLine_z]) rotate([0,90,skew+180]) cylinder(str_backlen,1,1);
}
//Case bottom:
color("brown",0.6) translate([-230,-100,-12.5-38]) cube([900+254,210+180,12.5]);

//Steel harp frame.
//Combination front rail & anvil:
color("gray",1.0) translate([0,0+strikeLine_y,-0+strikeLine_z-anvil_action_h-38]) rotate([90,0,0]) translate([-100,0,0]) difference(){
    cube([100+n_keys*13.75+63,38,38]);
    translate([-1,2.6,2.6]) cube([100+n_keys*13.75+63+2,38,38]);
}
//Right side harp end:
color("gray",1.0) translate([870,0+strikeLine_y,-0+strikeLine_z-anvil_action_h-38]) rotate([0,0,0]) difference(){
    cube([38,270,38]);
    translate([2.6,-1,2.6]) cube([38,270+2,38]);
}
//Skew-side harp frame:
color("gray",1.0) translate([-22,0+strikeLine_y,0+strikeLine_z-38]) rotate([0,0,skew]) translate([-110,0,0]) difference(){
    cube([1075,38,38]);
    translate([-1,2.6,2.6]) cube([1075+2,38,38]);
}

//Tuner pin block:
color("brown",0.8) translate([0-230,-30-22,-30]) cube([900,30,30]);
//Block for ball-ends and bridges:
//color("brown",0.8) translate([700-80-100,0,-30]) cube([350,220,30]);
color("brown",0.8) translate([900-27,0,-35.4]) cube([2*25.4,250,35.4]);

//
// Standard Piano Dimensions
white_key_width = 23.5;
// Black keys are usually centered on the gap, 
// but often offset slightly for visual balance.
// This array defines the offset of each semitone (0-11) from the start of the octave.
// Units are in "White Key Widths"
//octave_offsets = [
//    0,      // 0: C  (White)
//    0.6,    // 1: C# (Black) - shifted right
//    1,      // 2: D  (White)
//    1.65,   // 3: D# (Black) - shifted right
//    2,      // 4: E  (White)
//    3,      // 5: F  (White)
//    3.55,   // 6: F# (Black)
//    4,      // 7: G  (White)
//    4.6,    // 8: G# (Black)
//    5,      // 9: A  (White)
//    5.65,   // 10: A# (Black)
//    6       // 11: B  (White)
//];
octave_offsets = [
    0,      // 0: C  (White)
    7/12,    // 1: C# (Black) - shifted right
    14/12,      // 2: D  (White)
    21/12,   // 3: D# (Black) - shifted right
    28/12,      // 4: E  (White)
    35/12,      // 5: F  (White)
    42/12,   // 6: F# (Black)
    49/12,      // 7: G  (White)
    56/12,    // 8: G# (Black)
    63/12,      // 9: A  (White)
    70/12,   // 10: A# (Black)
    77/12       // 11: B  (White)
];
for (i = [0:1:(n_keys-1)]){
    // 1. Calculate Octave and Note Index
    octave = floor(i / 12);
    note_idx = i % 12; // 0=C, 1=C#, etc.
    
    // 2. Calculate Absolute X Position
    // Position = (Octaves * 7 * width) + (Note Offset * width)
    // NOTE: User has requested Uniform Mechanical Spacing of 13.75
    // so we use simple linear spacing for the mechanics:
    pos_x = i * 13.75;
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

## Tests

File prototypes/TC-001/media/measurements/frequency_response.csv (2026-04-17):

# Requirement: output from 100 Hz to 10 kHz
# Method: TODO (e.g. swept sine or pink noise playback through strings, FFT of pickup output)
measurement_id,pickup_config,frequency_Hz,amplitude_dBV,notes

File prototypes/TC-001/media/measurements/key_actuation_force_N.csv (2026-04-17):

# Requirement: keys play with 0.5 N of force
# Method: TODO (e.g. postal scale under key at full travel)
key_number,key_note,force_N,notes
# TODO: 60 rows, one per key (key 1 = F1, key 60 = E6)

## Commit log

2026-01-21 First mechanical OpenSCAD files
    [irkem_clavinetKey_v3_UChannel.scad, irkem_fullKeybed_v3.scad]
2026-01-21 Added first draft of the Bill of Materials (BOM)
    [TwinCl_BOM.xlsx]
2026-01-24 Initial design of laser-cut key combs
    [irkem_clavinetKey_v6.scad]
2026-01-27 Updated key file and rails to keybed
    Cut-down 2x4 key comb blocks added to design after single octave key action prototype
    [irkem_clavinetKey_v8_UChannel.scad, irkem_fullKeybed_v8.scad]
2026-01-27 Added staggered tuning pins and case
    [irkem_clavinetKey_v3_UChannel.scad, irkem_clavinetKey_v6.scad, irkem_clavinetKey_v8_UChannel.scad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]
2026-01-31 Added key cap files and build log pics
    [irkem_fullKeybed_v9.scad, irkem_keyCapsOctave_v0.scad, irkem_keycaps_v1.scad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]
2026-02-07 Updated hammer tips, added gitignore
    [irkem_A_keycapsToPrint_v2.scad, irkem_A_keycapsToPrint_v2.stl, irkem_A_keycapsToPrint_v4.scad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]
2026-02-17 Updated pivot and upstop combs
    [irkem_TPUtip_v0.scad, irkem_TPUtip_v0.stl, irkem_TPUtip_v1.scad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]
2026-03-12 TwinCl v2 design files and photos
    [irkem_Pickup_v0.scad, irkem_Pickup_v0.stl, irkem_PrStrEndBlck_v0.scad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]
2026-04-04 Flipped-harp qaXinet added
    [irkem_C_keycapsToPrint_v5.scad, irkem_C_keycapsToPrint_v5.stl, irkem_C_keycapsToPrint_v6.scad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]
2026-04-04 Resolving more conflicts
    [irkem_clavinetKey_v9_UChannel.scad, irkem_fullKeybed_v9.scad, irkem_keyCapsOctave_v0.scad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]
2026-04-17 Adding prototype build configuration definitions
    [StringLengths_v0.xlsx, TwinCl_BOM.xlsx, TwinCl_Requirements.xlsx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]
2026-04-18 Added recordings of the TC-002 prototype with jazzbass pickups and functions for spectral comparison with sim
2026-04-20 fitParametersTC002.m now works as intended. A set of best-fit parameters is also included in a mat file.
    [irkem_qaxinet_v3.scad, irkem_qaxinet_v4.scad]
2026-04-20 Claude built a sim-wav-render pipeline to generate sfz sample instruments to MIDI play-test in a sample-playback VST prior to physical builds
2026-04-20 Minor playability edits to sfz sample player config files
2026-08-17 Pickup bobbins, control box, eaton end strips, and more
    [irkem_A_keycapsToPrint_v6.stl, irkem_B_keycapsToPrint_v6.stl, irkem_C_keycapsForInt_v7.scad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]
